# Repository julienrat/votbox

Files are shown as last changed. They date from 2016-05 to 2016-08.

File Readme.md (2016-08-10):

Vot'Box - boitier de vote 
=

----
##Fonctionnement
### Connection à un réseau Wifi
Au démarrage si le boitier ne reconnait pas de wifi, les 2 leds (rouge et vertes) se metent à clignotter signalant que ce dernier est en mode de configuration.

Afin de connecter celui-ci à un réseau Wifi, il faut se connecter sur le SSID (Vot_box_XXXXXX ) et se rendre à l'adresse 192.168.4.1 pour accéder à l'interface de configuration.

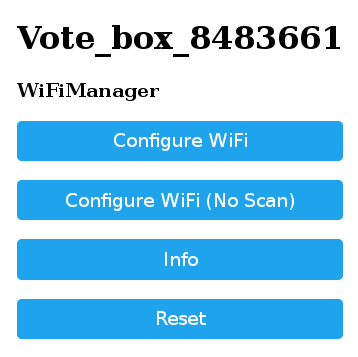
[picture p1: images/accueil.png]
accueil


Cliquez sur **Configure Wifi**

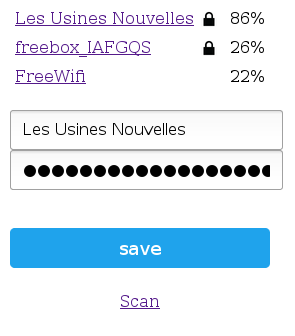
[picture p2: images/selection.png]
selection


Sélectionnez le réseau puis entrez votre mot de passe

Pour effacer les réseaux enregistrés, allumez le boitier en maintenant la touche **#** enfoncée.
###Utilisation
A l'allumage du boitier, la led verte se met à clignotter indiquant que celui-ci est en train de se connecter led . Si celui-ci trouve son réseau, la led arrete de clignotter et devient fixe led. Sinon, le boitier se met en point d'accès (les leds rouges et vertes clignottent led)

Pour voter, faites votre choix (chiffres et lettres). à la pression sur une touche, la led rouge se met à clignotter indiquant que le vote est mémorisé led. Pour modifier en cas d'erreur, appuyez sur la touche * . La led rouge s'eteint et permet de sélectionner une autre réponse led.

Pour valider et envoyer votre vote au serveur, appuyez sur la touche #. La led rouge arrete de clignotter et devient fixe led.  Il est alors impossible d'envoyer un autre vote.

###Remise à zero
Pour permettre un autre vote, l'animateur doit réinitialiser les boitiers en envoyant la requette : http://adresse_ip_boitier/RAZ la led rouge s'éteint et permet alors un nouveau voteled.

###Messages

Leds | Messages
------------ | --------------
led | Le boitier ne parvient pas à se connecter, Mode configuration en point d'accès 
led | Le boitier est en train de se connecter
led | Le boitier est connecté et est prêt à être utilisé 
led | Vote enregistré dans la mémoire mais pas envoyé au serveur
led | Vote effectué, attente de remise à zero

###Boitier 3D

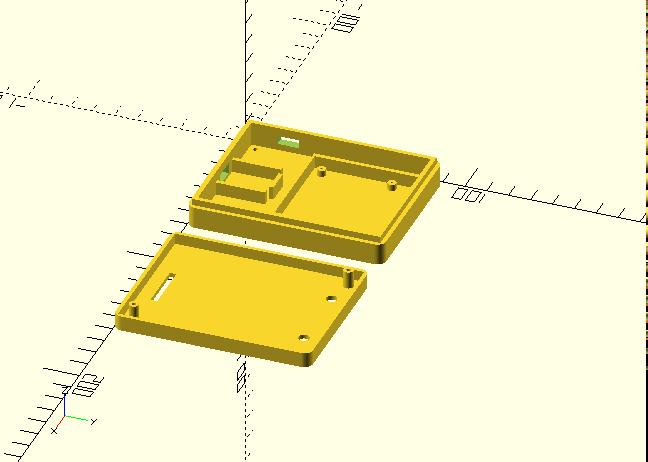
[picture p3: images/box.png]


###Schema de cablage
Fritzing | Eagle
---------|---------
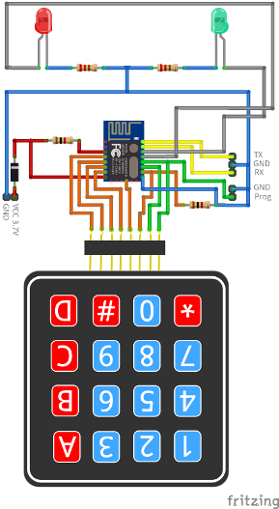
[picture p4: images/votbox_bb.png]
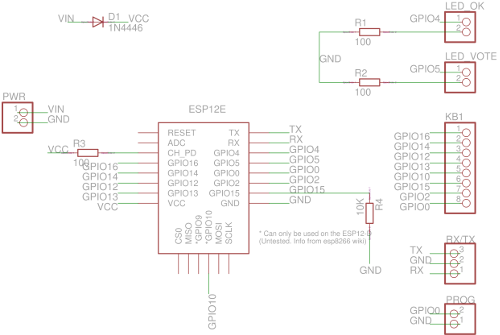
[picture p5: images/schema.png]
 |  

###Vue PCB
Top | Bottom 
---------|---------
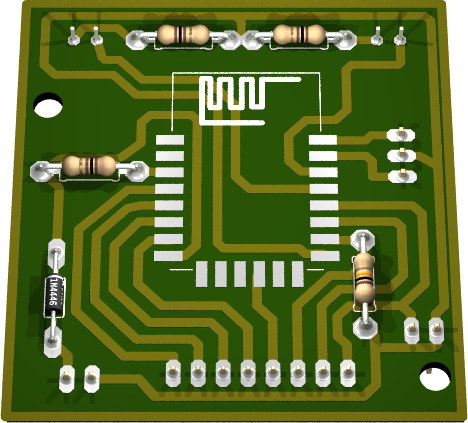
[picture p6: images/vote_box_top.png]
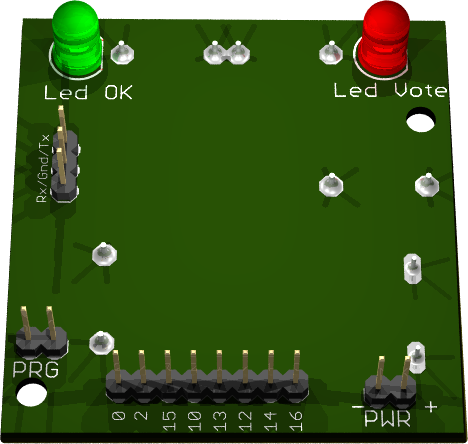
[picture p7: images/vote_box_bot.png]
 |

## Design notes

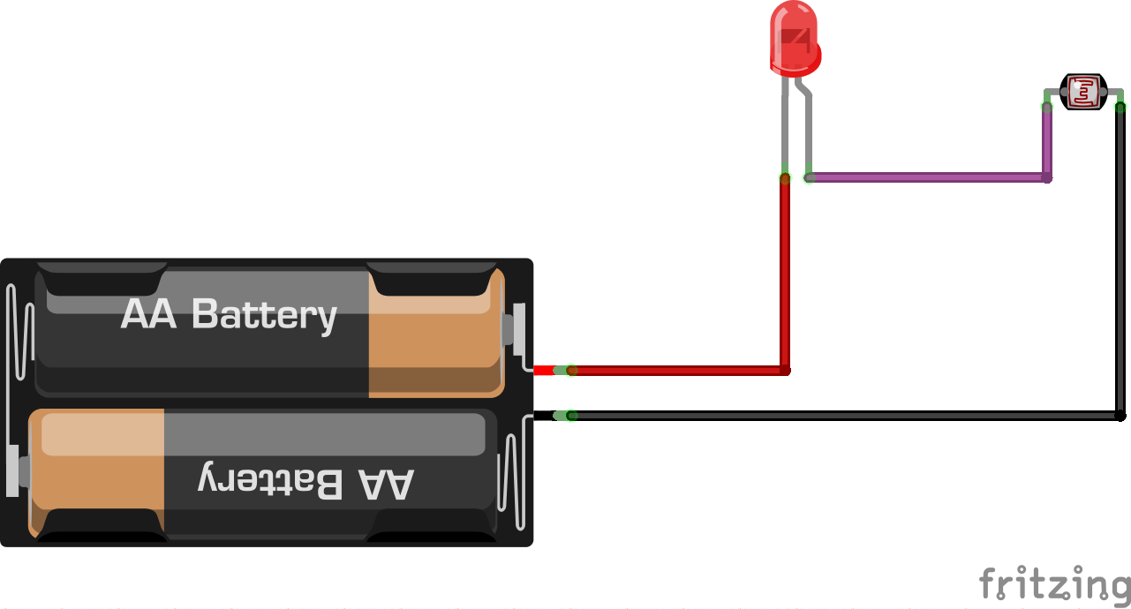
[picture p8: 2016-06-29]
images/shema_photoR.png

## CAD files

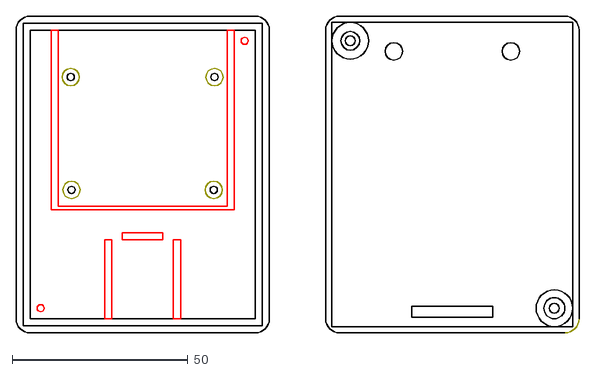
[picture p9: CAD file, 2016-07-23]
3D_printed_case/#vote_box.dxf
160.0 x 90.0

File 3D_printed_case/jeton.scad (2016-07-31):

//cylinder(d=23.21,h=2);
$fn=100;
linear_extrude(height = 2, center = false, convexity = 100)
   import (file = "jeton.dxf",layer="0"); 

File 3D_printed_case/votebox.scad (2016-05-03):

$fn=100;
difference(){

union(){
 linear_extrude(height = 2, center = false, convexity = 30)
   import (file = "vote_box.dxf",layer="0");
   
    linear_extrude(height = 13, center = false, convexity = 30)
   import (file = "vote_box.dxf",layer="int");
   
   #    linear_extrude(height = 10, center = false, convexity = 30)
   import (file = "vote_box.dxf",layer="ext");
   
    linear_extrude(height = 8, center = false, convexity = 30)
   import (file = "vote_box.dxf",layer="case_int");
    
     linear_extrude(height = 5, center = false, convexity = 30)
   import (file = "vote_box.dxf",layer="pcb_holder");
    
         linear_extrude(height = 7, center = false, convexity = 30)
   import (file = "vote_box.dxf",layer="capot");
    
             linear_extrude(height = 2, center = false, convexity = 30)
   import (file = "vote_box.dxf",layer="capot _ fond");
    union(){
       linear_extrude(height = 10, center = false, convexity = 30)
   import (file = "vote_box.dxf",layer="capot_fix");
          linear_extrude(height = 4, center = false, convexity = 30)
   import (file = "vote_box.dxf",layer="capot_fix_reforts");
    }
   
}
translate([72/2-10/2,0,3.5]) cube([10,10,5]);
translate([0,16,5]) cube([10,10,4]);
}
   

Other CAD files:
3D_printed_case/vote_box.dxf

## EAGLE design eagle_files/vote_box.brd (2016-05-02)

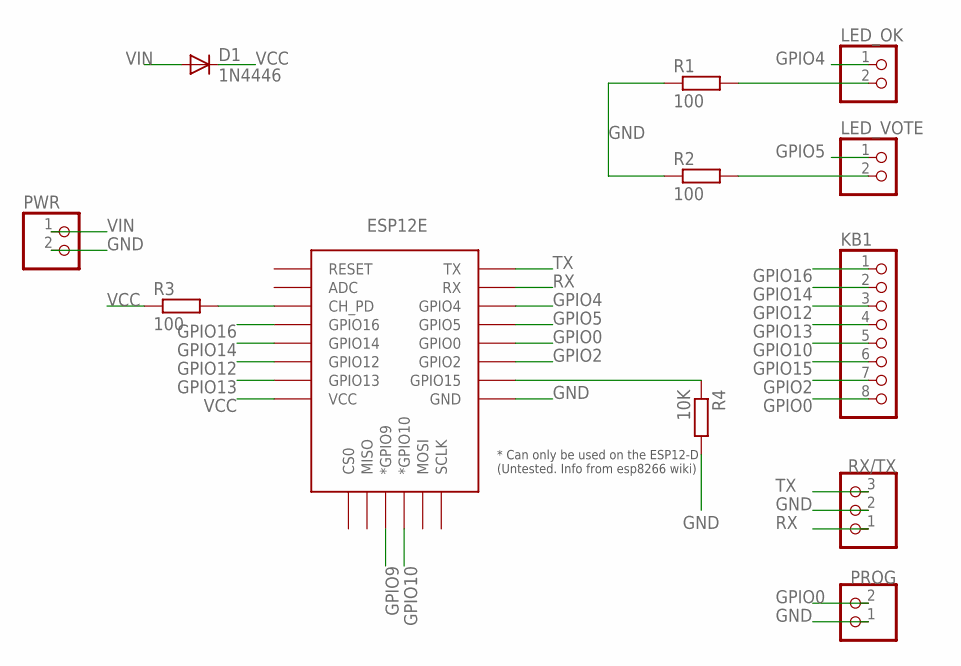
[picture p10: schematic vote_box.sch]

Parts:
D1: 1N4446; DO35-10
ESP12E: ESP12ESMD; ESP12E-SMD
KB1: PINHD-1X8; 1X08
LED_OK: PINHD-1X2; 1X02
LED_VOTE: PINHD-1X2; 1X02
PROG: PINHD-1X2; 1X02
PWR: PINHD-1X2; 1X02
R1, R2, R3: 100; 0207/10
R4: 10K; 0207/10
RX/TX: PINHD-1X3; 1X03

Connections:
GND: ESP12E.GND, PROG.1, PWR.2, R1.1, R2.1, R4.2, RX/TX.2
GPIO0: ESP12E.GPIO0, KB1.8, PROG.2
GPIO2: ESP12E.GPIO2, KB1.7
GPIO4: ESP12E.GPIO4, LED_OK.1
GPIO5: ESP12E.GPIO5, LED_VOTE.1
GPIO9: ESP12E.GPIO9 (*GPIO9)
GPIO10: ESP12E.GPIO10 (*GPIO10), KB1.5
GPIO12: ESP12E.GPIO12, KB1.3
GPIO13: ESP12E.GPIO13, KB1.4
GPIO14: ESP12E.GPIO14, KB1.2
GPIO15: ESP12E.GPIO15, KB1.6, R4.1
GPIO16: ESP12E.GPIO16, KB1.1
unnamed: ESP12E.CH_PD, R3.2
unnamed: LED_VOTE.2, R2.2
unnamed: LED_OK.2, R1.2
RX: ESP12E.RXD0 (RX), RX/TX.1
TX: ESP12E.TXD0 (TX), RX/TX.3
VCC: D1.C, ESP12E.VCC, R3.1
VIN: D1.A, PWR.1

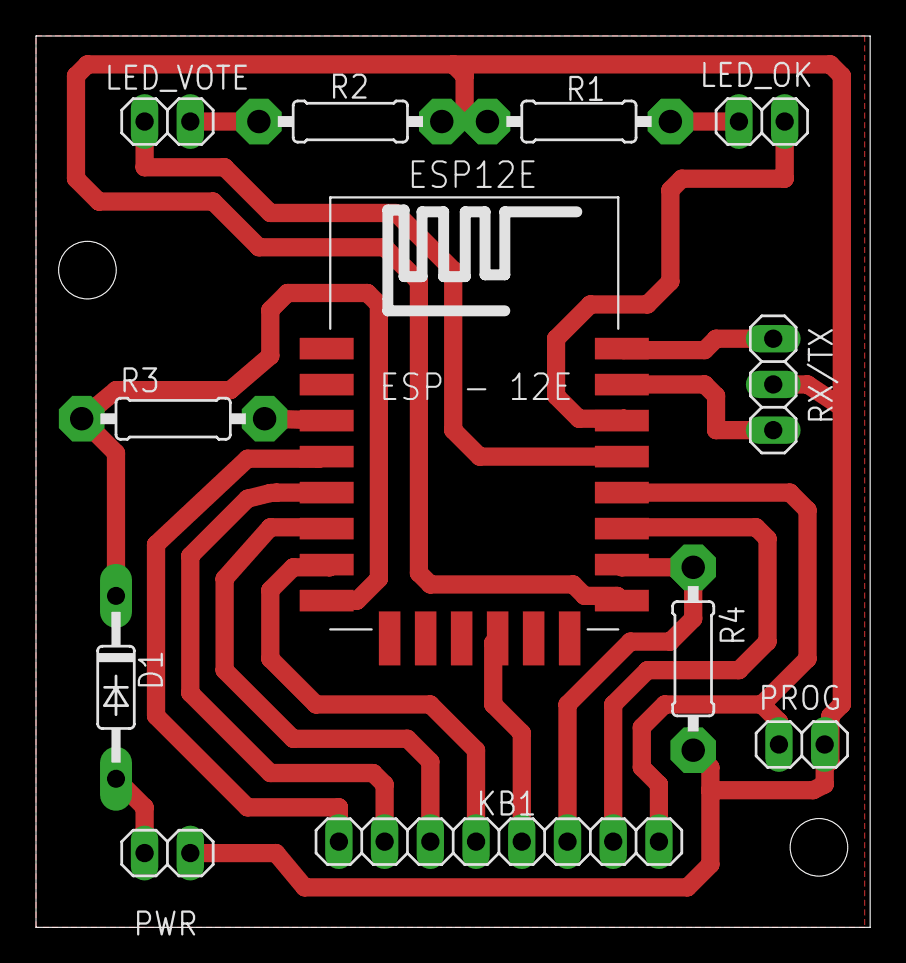
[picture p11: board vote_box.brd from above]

Board: 2 copper layers, 46.3 x 49.5 mm, 12 parts (0 on the bottom side), 18 nets.

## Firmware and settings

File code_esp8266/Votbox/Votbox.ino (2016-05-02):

// Bibliothèques WIFI
#include <ESP8266WiFi.h>
#include <ESP8266HTTPClient.h>

const char* ssid = "ssid";
const char* password = "********";

#include <Ticker.h>
Ticker connect_blink; // clignotements led Verte
Ticker vote_blink; // clignotements led Rouge

WiFiServer server(80); // serveur de remise à zero

String http_site = "http://moumoute.biz/sondage_sms_2/smswall/add_sms.php?phrases="; // url du site de vote


char* vote = ""; // vote en cours
int voted = 0; // a voté
const int LED_VERTE = 4;
const int LED_ROUGE = 5;

void tick_V()
{
  //toggle state
  int state = digitalRead(LED_VERTE);  
  digitalWrite(LED_VERTE, !state);     
}

void tick_R()
{
  //toggle state
  int state = digitalRead(LED_ROUGE);  
  digitalWrite(LED_ROUGE, !state);     
}

void envoi_get(String val) // fonction d'envoi get au site php
{
  HTTPClient http;
  http.setReuse(true);
  http.begin(http_site + val); //HTTP
  int httpCode = http.GET();
  http.end();
}

void setup() {
  Serial.begin(115200);
  delay(800);
  Serial.println("Vot'Box Version 1.1");
  connect_blink.attach(0.6, tick_V);

  // Initialisation des soties LEDS
  pinMode(LED_VERTE, OUTPUT); // led verte
  pinMode(LED_ROUGE, OUTPUT); // led rouge


  // Initialisation du clavier
  pinMode(13, OUTPUT); // colonne des 1 4 7 *
  pinMode(12, OUTPUT); // colonne des 2 5 8 0
  pinMode(14, OUTPUT); // colonne des 3 6 9 #
  pinMode(16, OUTPUT); // colonne des A B C D

  pinMode(0, INPUT_PULLUP); // ligne des 1 2 3 A
  pinMode(2, INPUT_PULLUP); // ligne des 4 5 6 B
  pinMode(10, INPUT_PULLUP); // ligne des 7 8 9 C
  pinMode(3, INPUT_PULLUP); // ligne des * 0 # D (ATTENTION : sortie RX à remplacer dans la V2 GPIO15)

  // Initialisation du WIFI
  WiFi.begin(ssid, password);
  Serial.println();
  Serial.println("Attente de connection au réseau... ");

  while (WiFi.status() != WL_CONNECTED) {
    delay(500);
    Serial.print(".");
  }
  Serial.println();
  Serial.print("Connecté au réseau : ");
  Serial.println(ssid);
  Serial.println(WiFi.localIP());
  server.begin();
  connect_blink.detach();
}


int keyboard() {

  int touche = 5555;
  /* Principe on balaye les colonne et on tcheck si une ligne est appuyée
     = 14 ; # = 15 ; A = 19 ; B = 18 ; C = 17 ;  D = 16 */
  // colonne des 1 4 7 *
  digitalWrite(13, LOW);
  digitalWrite(12, HIGH);
  digitalWrite(14, HIGH);
  digitalWrite(16, HIGH);

  if (!digitalRead(3)) touche = 14; // *
  if (!digitalRead(10)) touche = 7;
  if (!digitalRead(2)) touche = 4;
  if (!digitalRead(0)) touche = 1;

  // colonne des 2 5 8 0
  digitalWrite(13, HIGH);
  digitalWrite(12, LOW);
  digitalWrite(14, HIGH);
  digitalWrite(16, HIGH);

  if (!digitalRead(3)) touche = 0;
  if (!digitalRead(10)) touche = 8;
  if (!digitalRead(2)) touche = 5;
  if (!digitalRead(0)) touche = 2;

  // colonne des 3 6 9 #
  digitalWrite(13, HIGH);
  digitalWrite(12, HIGH);
  digitalWrite(14, LOW);
  digitalWrite(16, HIGH);

  if (!digitalRead(3)) touche = 15; // #HTTPClient
  if (!digitalRead(10)) touche = 9;
  if (!digitalRead(2)) touche = 6;
  if (!digitalRead(0)) touche = 3;

  // colonne des A B C D
  digitalWrite(13, HIGH);
  digitalWrite(12, HIGH);
  digitalWrite(14, HIGH);
  digitalWrite(16, LOW);

  if (!digitalRead(3)) touche = 16; //D
  if (!digitalRead(10)) touche = 17; // C
  if (!digitalRead(2)) touche = 18; // B
  if (!digitalRead(0)) touche = 19; // A
  return touche;

}

void loop() {
  String req = "";
  WiFiClient client = server.available(); // test de la requete sur le serveur
  if (client) {
    req = client.readStringUntil('\r'); // récupération de la requette
  }

  if (req.indexOf("/RAZ") != -1) { //Si RAZ alors on remets tout à zero !
    voted = 0;
    String s = "HTTP/1.1 200 OK\r\n";
    s += "Content-Type: text/html\r\n\r\n";
    s += "<html>\n";
    s += "ok;" ;
    s += vote;
    s += "</html>\n";
    client.print(s);
    delay(1);
    client.flush();
    digitalWrite(LED_ROUGE, LOW);
    vote = "";
  }
  if (WiFi.status() != 3) {
    digitalWrite(LED_VERTE, HIGH);
    delay(600);
    digitalWrite(LED_VERTE, LOW);
    delay(600);
  } else {
    digitalWrite(LED_VERTE, HIGH);
  }


  int val_keyboard = keyboard();

  if (val_keyboard != 5555 && voted == 0) {
    Serial.println(val_keyboard);
    switch (val_keyboard) {
      case 14: // correction du vote
        vote = "";
        vote_blink.detach();
        digitalWrite(LED_ROUGE, LOW);
        delay(300);
        break;
      case 15: // envoi du vote
        if (vote != "") {
          Serial.println("envoi du vote");
          Serial.println(vote);
          envoi_get(vote);
          vote_blink.detach();
          digitalWrite(LED_ROUGE, HIGH);
          voted = 1;
        }
        break;
      case 19:
        if (vote == "") {
          vote_blink.attach(0.3, tick_R);
          vote = "A";
        }
        break;
      case 18:
        if (vote == "") {
          vote_blink.attach(0.3, tick_R);
          vote = "B";
        }
        break;
      case 17:
        if (vote == "") {
          vote_blink.attach(0.3, tick_R);
          vote = "C";
        }
        break;
      case 16:
        if (vote == "") {
          vote_blink.attach(0.3, tick_R);
          vote = "D";
        }
        break;
      case 1:
        if (vote == "") {
          vote_blink.attach(0.3, tick_R);
          vote = "1";
        }
        break;
      case 2:
        if (vote == "") {
          vote_blink.attach(0.3, tick_R);
          vote = "2";
        }
        break;
      case 3:
        if (vote == "") {
          vote_blink.attach(0.3, tick_R);
          vote = "3";
        }
        break;
      case 4:
        if (vote == "") {
          vote_blink.attach(0.3, tick_R);
          vote = "4";
        }
        break;
      case 5:
        if (vote == "") {
          vote_blink.attach(0.3, tick_R);
          vote = "5";
        }
        break;
      case 6:
        if (vote == "") {
          vote_blink.attach(0.3, tick_R);
          vote = "6";
        }
        break;
      case 7:
        if (vote == "") {
          vote_blink.attach(0.3, tick_R);
          vote = "7";
        }
        break;
      case 8:
        if (vote == "") {
          vote_blink.attach(0.3, tick_R);
          vote = "8";
        }
        break;
      case 9:
        if (vote == "") {
          vote_blink.attach(0.3, tick_R);
          vote = "9";
        }
        break;
      case 0:
        if (vote == "") {
          vote_blink.attach(0.3, tick_R);
          vote = "0";
        }
        break;
    }
  }
}

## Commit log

2016-05-02 + ‘.sparkleshare’ + ‘SparkleShare.txt’
2016-05-02 + ‘code_esp8266/’
2016-05-02 + ‘code_esp8266/Votbox/Votbox.ino’ + ‘code_esp8266/Votbox_autoconnect/Votbox_autoconnect.ino’
2016-05-02 + ‘eagle_files/’
2016-05-02 + ‘3D_printed_case/’
2016-05-02 + ‘3D_printed_case/vote_box.dxf’ + ‘3D_printed_case/votebox.scad’
    [vote_box.dxf, votebox.scad]
2016-05-02 + ‘eagle_files/vote_box.brd’ + ‘eagle_files/vote_box.sch’
    [vote_box.brd, vote_box.sch]
2016-05-02 / ‘code_esp8266/Votbox_autoconnect/Votbox_autoconnect.ino’
2016-05-02 + ‘Readme.txt’
2016-05-02 / ‘Readme.txt’
2016-05-02 < ‘Readme.txt’ > ‘Readme.md’
2016-05-02 / ‘Readme.md’
2016-05-02 + ‘images/’
2016-05-02 + ‘images/accueil.png’ + ‘images/leds_ap.png’ + ‘images/leds_connect.png’ + ‘images/leds_ok.png’ + ‘images/leds_vote_mem.png’ + ‘images/selection.png’
2016-05-02 + ‘images/leds_voted.png’
2016-05-02 + ‘3D_printed_case/#vote_box.dxf’
    [#vote_box.dxf]
2016-05-02 - ‘3D_printed_case/#vote_box.dxf’ / ‘3D_printed_case/vote_box.dxf’
    [#vote_box.dxf, vote_box.dxf]
2016-05-02 / ‘3D_printed_case/vote_box.dxf’
    [vote_box.dxf]
2016-05-02 / ‘3D_printed_case/#vote_box.dxf’
    [#vote_box.dxf]
2016-05-02 / ‘3D_printed_case/votebox.scad’
    [votebox.scad]
2016-05-02 + ‘3D_printed_case/votebox.stl’
    [votebox.stl]
2016-05-02 + ‘3D_printed_case/votebox_capot.stl’
    [votebox_capot.stl]
2016-05-02 + ‘3D_printed_case/votebox_fond.stl’
    [votebox_fond.stl]
2016-05-02 / ‘3D_printed_case/votebox.stl’
    [votebox.stl]
2016-05-02 + ‘3D_printed_case/box’
2016-05-02 + ‘3D_printed_case/box.png’
2016-05-02 < ‘3D_printed_case/box.png’ > ‘images/box.png’
2016-05-02 - ‘3D_printed_case/box’
2016-05-02 / ‘code_esp8266/Votbox/Votbox.ino’
2016-05-03 - ‘3D_printed_case/votebox.stl’ - ‘3D_printed_case/votebox_capot.stl’ - ‘3D_printed_case/votebox_fond.stl’
    [votebox.stl, votebox_capot.stl, votebox_fond.stl]
2016-05-03 + ‘New Folder/’
2016-05-03 < ‘New Folder/’ > ‘fritzing/’
2016-05-03 + ‘fritzing/votbox.fzz’
    [votbox.fzz]
2016-05-03 / ‘fritzing/votbox.fzz’
    [votbox.fzz]
2016-05-03 + ‘images/votbox_bb.png’
2016-05-03 / ‘images/votbox_bb.png’
2016-05-03 + ‘images/schema.png’
2016-06-29 + ‘images/shema_photoR.png’
2016-07-31 + ‘3D_printed_case/jeton.scad’
    [jeton.scad]
2016-08-10 + ‘images/vote_box_bot.png’ + ‘images/vote_box_top.png’
2016-08-10 / ‘images/leds_vote_mem.png’
2016-08-10 / ‘images/leds_voted.png’
2016-08-10 / ‘images/leds_ok.png’
2016-08-10 / ‘images/leds_connect.png’
2016-08-10 / ‘images/leds_ap.png’
2016-08-10 / ‘images/vote_box_top.png’
2016-08-10 / ‘images/vote_box_bot.png’
